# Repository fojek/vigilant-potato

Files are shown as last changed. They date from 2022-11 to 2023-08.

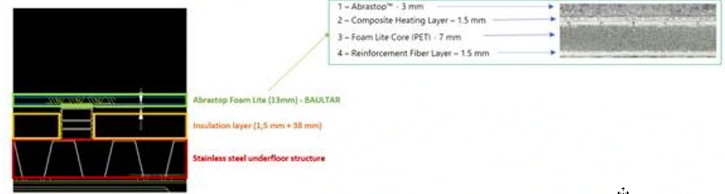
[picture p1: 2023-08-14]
Isolation WMATA.PNG

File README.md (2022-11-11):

# vigilant-potato
Capteur WiFi générique pour la cabane

* WIFI : ESP-12F ou ESP-M3
* MCU : Atmel ou ESP ou STM
* DC/DC à partir d'une alimentation 24V
* Adresse modifiable, par exemple DIP switch rotative

* Possibilité de lire: 
- distance ; 
- température ; 
- pression ;
- 2 entrées digitales ;

* Possibilité d'écrire :
- deux sorties relais?

Capteur ultrason modulaire (et autres capteurs)

Affichage de l'état : 
 - Vert clignotant : ON et en train de se connecter
 - Vert solide : ON et connecté
 - Autre led : Rouge si erreur (ou la même avec une autre séquence)
 - Autre led : trig effectué (distance)

Todo
- [ ] Déterminer un format
- [ ] Choisir ESP et MCU
- [ ] Choisir capteur ultrason
- [ ] Fabriquer PCB et tester

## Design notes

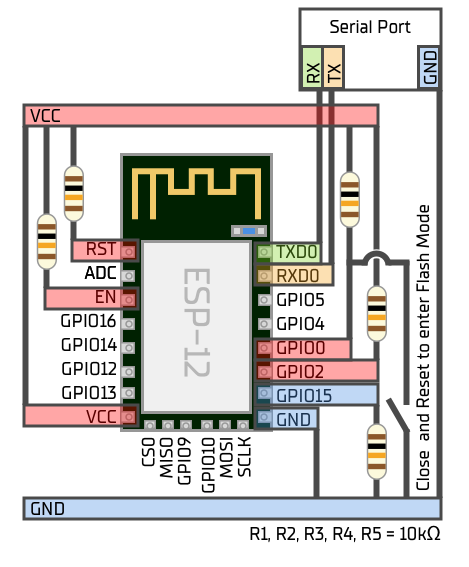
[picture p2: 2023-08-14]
Flash-ESP12.PNG

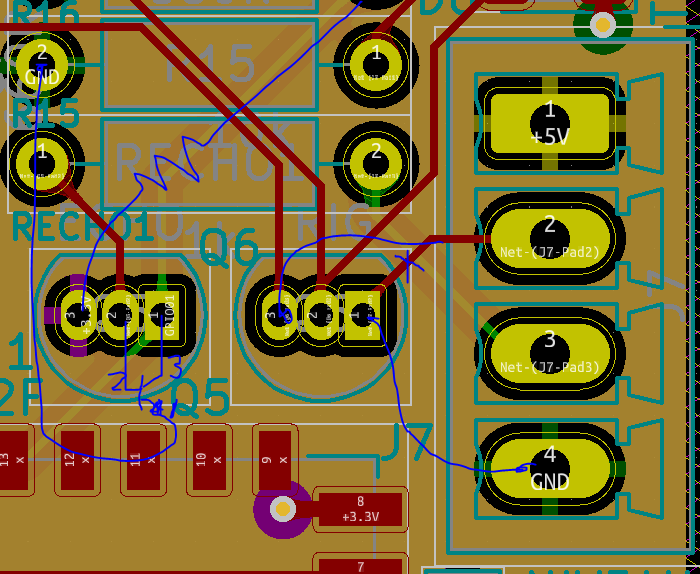
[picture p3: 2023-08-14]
modifs gerber.PNG

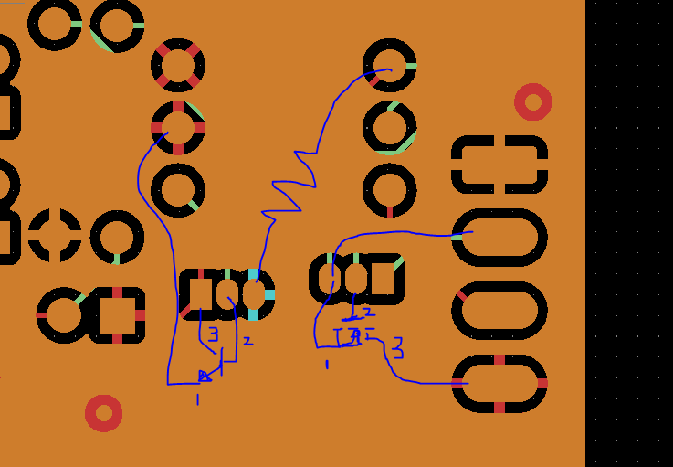
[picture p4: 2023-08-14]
modifs gerber (v1).PNG

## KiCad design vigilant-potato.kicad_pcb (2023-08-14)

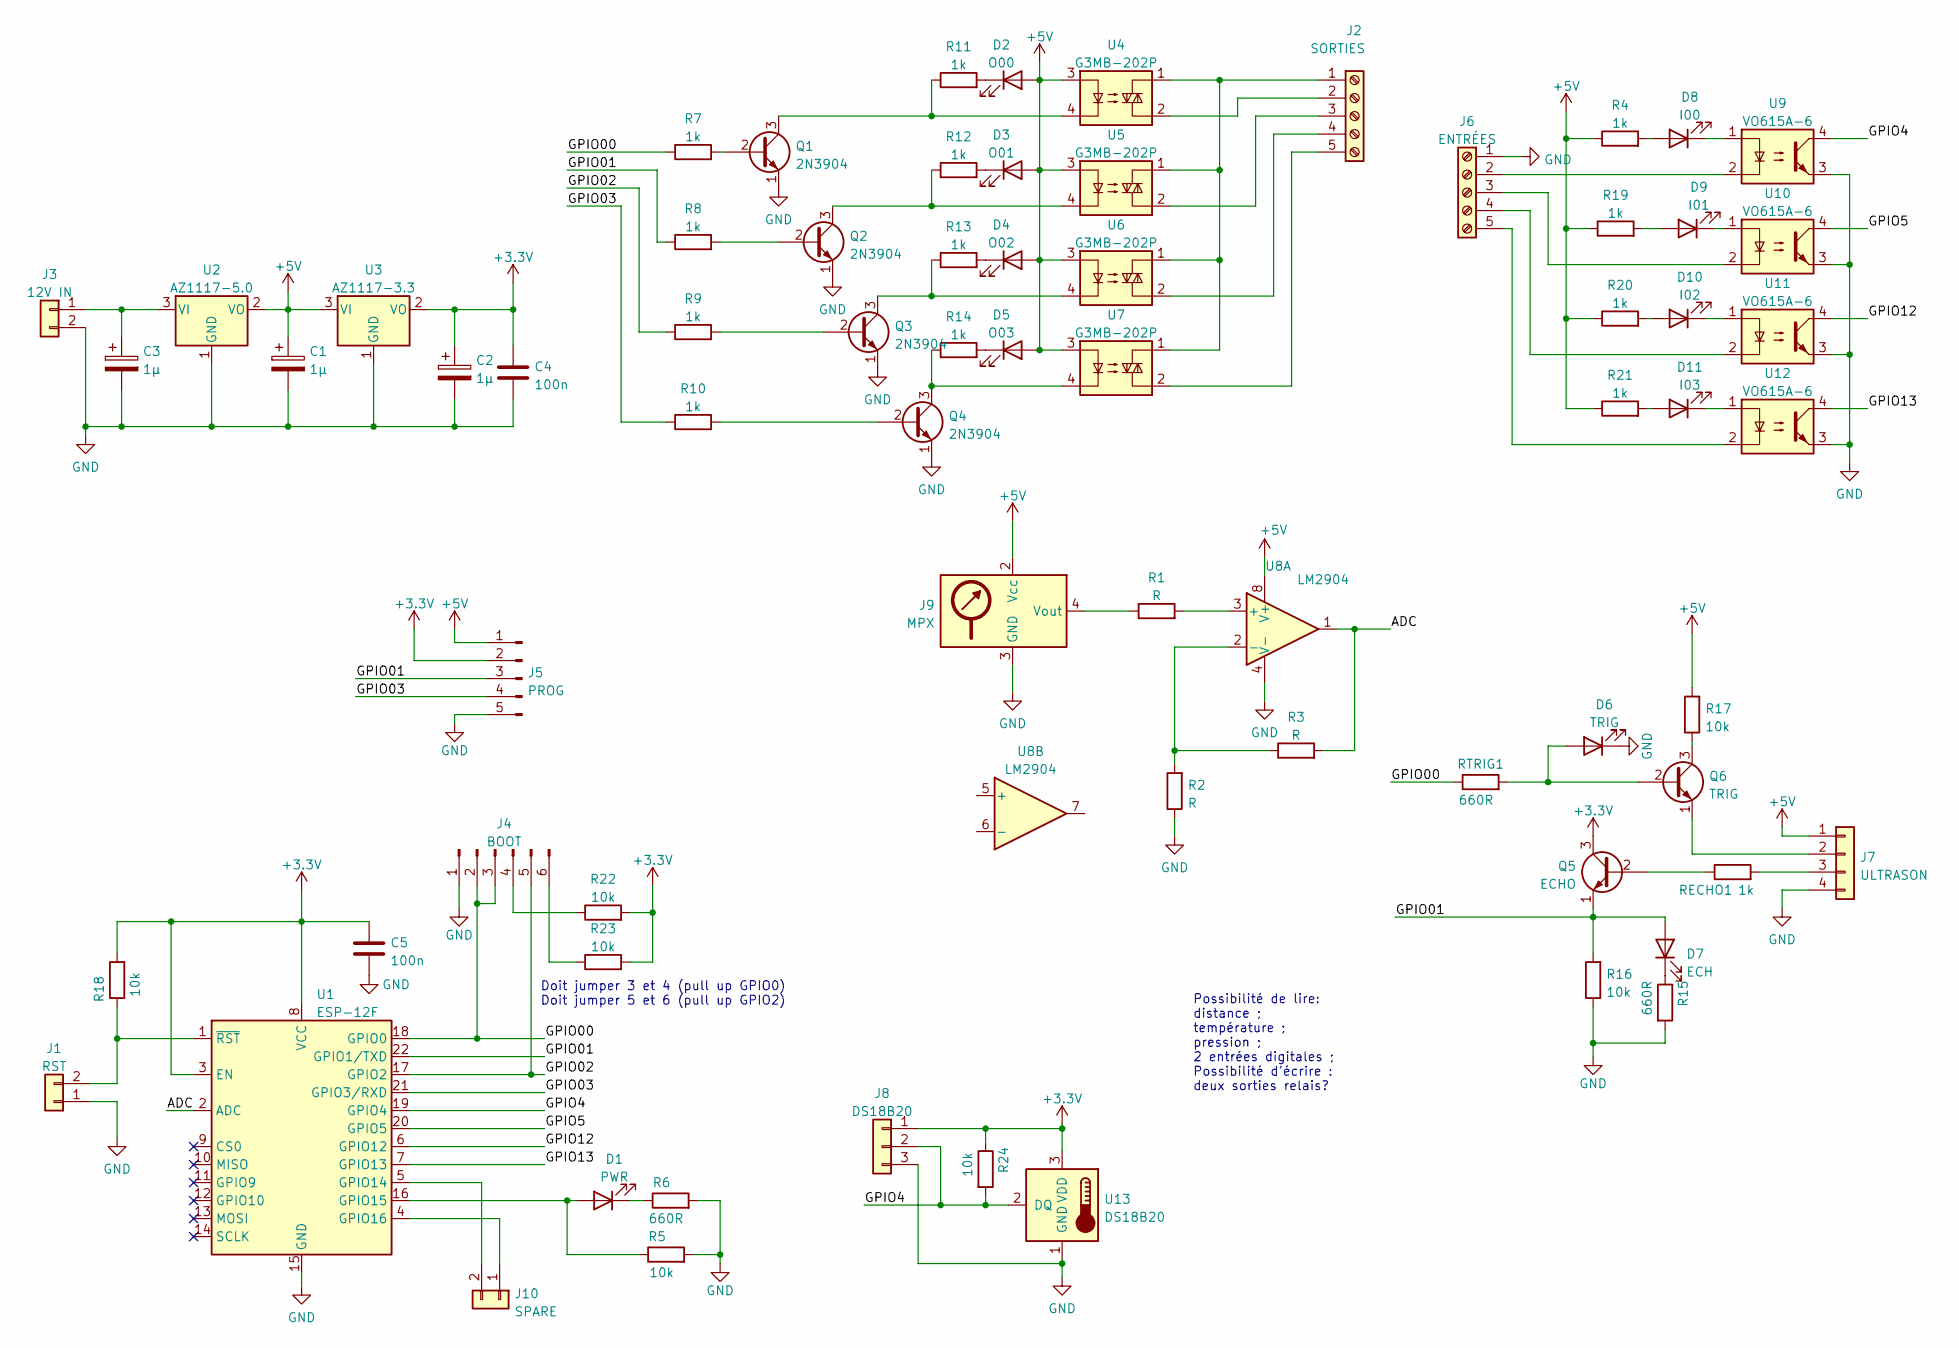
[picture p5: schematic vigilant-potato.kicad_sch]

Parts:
C1, C2, C3: 1µ; C_Rect_L7.0mm_W2.0mm_P5.00mm
C4, C5: 100n; C_Rect_L7.0mm_W2.0mm_P5.00mm
D1: PWR; LED_1206_3216Metric_Pad1.42x1.75mm_HandSolder
D2: O00; LED_1206_3216Metric_Pad1.42x1.75mm_HandSolder
D3: O01; LED_1206_3216Metric_Pad1.42x1.75mm_HandSolder
D4: O02; LED_1206_3216Metric_Pad1.42x1.75mm_HandSolder
D5: O03; LED_1206_3216Metric_Pad1.42x1.75mm_HandSolder
D6: TRIG; LED_1206_3216Metric_Pad1.42x1.75mm_HandSolder
D7: ECH; LED_1206_3216Metric_Pad1.42x1.75mm_HandSolder
D8: I00; LED_1206_3216Metric_Pad1.42x1.75mm_HandSolder
D9: I01; LED_1206_3216Metric_Pad1.42x1.75mm_HandSolder
D10: I02; LED_1206_3216Metric_Pad1.42x1.75mm_HandSolder
D11: I03; LED_1206_3216Metric_Pad1.42x1.75mm_HandSolder
J1: RST; PinHeader_1x02_P2.54mm_Vertical
J2: SORTIES; PhoenixContact_MCV_1,5_5-G-3.5_1x05_P3.50mm_Vertical; part EBRA-05-A
J3: 12V IN; PhoenixContact_MCV_1,5_2-G-3.5_1x02_P3.50mm_Vertical; part EBRA-02-A
J4: BOOT; PinHeader_1x06_P2.54mm_Vertical
J5: PROG; PinHeader_1x05_P2.54mm_Vertical
J6: ENTRÉES; PhoenixContact_MCV_1,5_5-G-3.5_1x05_P3.50mm_Vertical; part EBRA-05-A
J7: ULTRASON; PhoenixContact_MCV_1,5_4-G-3.5_1x04_P3.50mm_Vertical; part EBRA-04-A
J8: DS18B20; PinSocket_1x03_P2.54mm_Vertical
J9: MPX; PinHeader_1x06_P2.54mm_Vertical
J10: SPARE; PinHeader_1x02_P2.54mm_Vertical
Q1, Q2, Q3, Q4: 2N3904; TO-92_Inline
Q5: ECHO; TO-92_Inline
Q6: TRIG; TO-92_Inline
R1, R2, R3: R; R_Axial_DIN0207_L6.3mm_D2.5mm_P10.16mm_Horizontal
R4, R11, R12, R13, R14, R19, R20, R21: 1k; R_0805_2012Metric_Pad1.20x1.40mm_HandSolder
R5, R18, R22, R23: 10k; R_0805_2012Metric_Pad1.20x1.40mm_HandSolder
R6: 660R; R_0805_2012Metric_Pad1.20x1.40mm_HandSolder
R7, R8, R9, R10: 1k; R_Axial_DIN0207_L6.3mm_D2.5mm_P10.16mm_Horizontal
R15: 660R; R_Axial_DIN0207_L6.3mm_D2.5mm_P10.16mm_Horizontal
R16, R17, R24: 10k; R_Axial_DIN0207_L6.3mm_D2.5mm_P10.16mm_Horizontal
RECHO1: 1k; R_Axial_DIN0207_L6.3mm_D2.5mm_P10.16mm_Horizontal
RTRIG1: 660R; R_Axial_DIN0207_L6.3mm_D2.5mm_P10.16mm_Horizontal
U1: ESP-12F; ESP-12E
U2: AZ1117-5.0; TO-252-2
U3: AZ1117-3.3; TO-252-2
U4, U5, U6, U7: G3MB-202P
U8: LM2904; SOIC-8_3.9x4.9mm_P1.27mm
U9, U10, U11, U12: VO615A-6; DIP-4_W7.62mm
U13: DS18B20; TO-92_Inline

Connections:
+3.3V: C2.1, C4.1, C5.1, J5.2, J8.1, Q5.3 (C), R18.2, R22.2, R23.2, R24.1, U1.3 (EN), U1.8 (VCC), U3.2 (VO), U13.3 (VDD)
+5V: C1.1, D2.2 (A), D3.2 (A), D4.2 (A), D5.2 (A), J5.1, J7.1, J9.2 (Vcc), R4.1, R17.2, R19.1, R20.1, R21.1, U2.2 (VO), U3.3 (VI), U4.3, U5.3, U6.3, U7.3, U8.8 (V+)
/ADC: R3.2, U1.2 (ADC), U8.1
/GPIO00: J4.2, J4.3, R7.1, RTRIG1.1, U1.18 (GPIO0)
/GPIO01: D7.2 (A), J5.3, Q5.1 (E), R8.1, R16.2, U1.22 (GPIO1/TXD)
/GPIO02: J4.5, R9.1, U1.17 (GPIO2)
/GPIO03: J5.4, R10.1, U1.21 (GPIO3/RXD)
/GPIO4: J8.2, R24.2, U1.19 (GPIO4), U9.4, U13.2 (DQ)
/GPIO5: U1.20 (GPIO5), U10.4
/GPIO12: U1.6 (GPIO12), U11.4
/GPIO13: U1.7 (GPIO13), U12.4
GND: C1.2, C2.2, C3.2, C4.2, C5.2, D6.1 (K), J1.1, J3.2, J4.1, J5.5, J6.1, J7.4, J8.3, J9.3 (GND), Q1.1 (E), Q2.1 (E), Q3.1 (E), Q4.1 (E), R2.1, R5.2, R6.2, R15.2, R16.1, U1.15 (GND), U2.1 (GND), U3.1 (GND), U8.4 (V-), U9.3, U10.3, U11.3, U12.3, U13.1 (GND)
unnamed: C3.1, J3.1, U2.3 (VI)
unnamed: D1.1 (K), R6.1
unnamed: D1.2 (A), R5.1, U1.16 (GPIO15)
unnamed: D2.1 (K), R11.2
unnamed: D3.1 (K), R12.2
unnamed: D4.1 (K), R13.2
unnamed: D5.1 (K), R14.2
unnamed: D6.2 (A), Q6.2 (B), RTRIG1.2
unnamed: D7.1 (K), R15.1
unnamed: D8.1 (K), U9.1
unnamed: D8.2 (A), R4.2
unnamed: D9.1 (K), U10.1
unnamed: D9.2 (A), R19.2
unnamed: D10.1 (K), U11.1
unnamed: D10.2 (A), R20.2
unnamed: D11.1 (K), U12.1
unnamed: D11.2 (A), R21.2
unnamed: J1.2, R18.1, U1.1 (~RST)
unnamed: J2.1, U4.1, U5.1, U6.1, U7.1
unnamed: J2.2, U4.2
unnamed: J2.3, U5.2
unnamed: J2.4, U6.2
unnamed: J2.5, U7.2
unnamed: J4.4, R22.1
unnamed: J4.6, R23.1
unnamed: J6.2, U9.2
unnamed: J6.3, U10.2
unnamed: J6.4, U11.2
unnamed: J6.5, U12.2
unnamed: J7.2, Q6.1 (E)
unnamed: J7.3, RECHO1.2
unnamed: J9.4 (Vout), R1.1
unnamed: J10.1, U1.4 (GPIO16)
unnamed: J10.2, U1.5 (GPIO14)
unnamed: Q1.2 (B), R7.2
unnamed: Q1.3 (C), R11.1, U4.4
unnamed: Q2.2 (B), R8.2
unnamed: Q2.3 (C), R12.1, U5.4
unnamed: Q3.2 (B), R9.2
unnamed: Q3.3 (C), R13.1, U6.4
unnamed: Q4.2 (B), R10.2
unnamed: Q4.3 (C), R14.1, U7.4
unnamed: Q5.2 (B), RECHO1.1
unnamed: Q6.3 (C), R17.1
unnamed: R1.2, U8.3 (+)
unnamed: R2.2, R3.1, U8.2 (-)

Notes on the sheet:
Doit jumper 3 et 4 (pull up GPIO0) Doit jumper 5 et 6 (pull up GPIO2)
Possibilité de lire: distance ; température ; pression ; 2 entrées digitales ; Possibilité d'écrire : deux sorties relais?

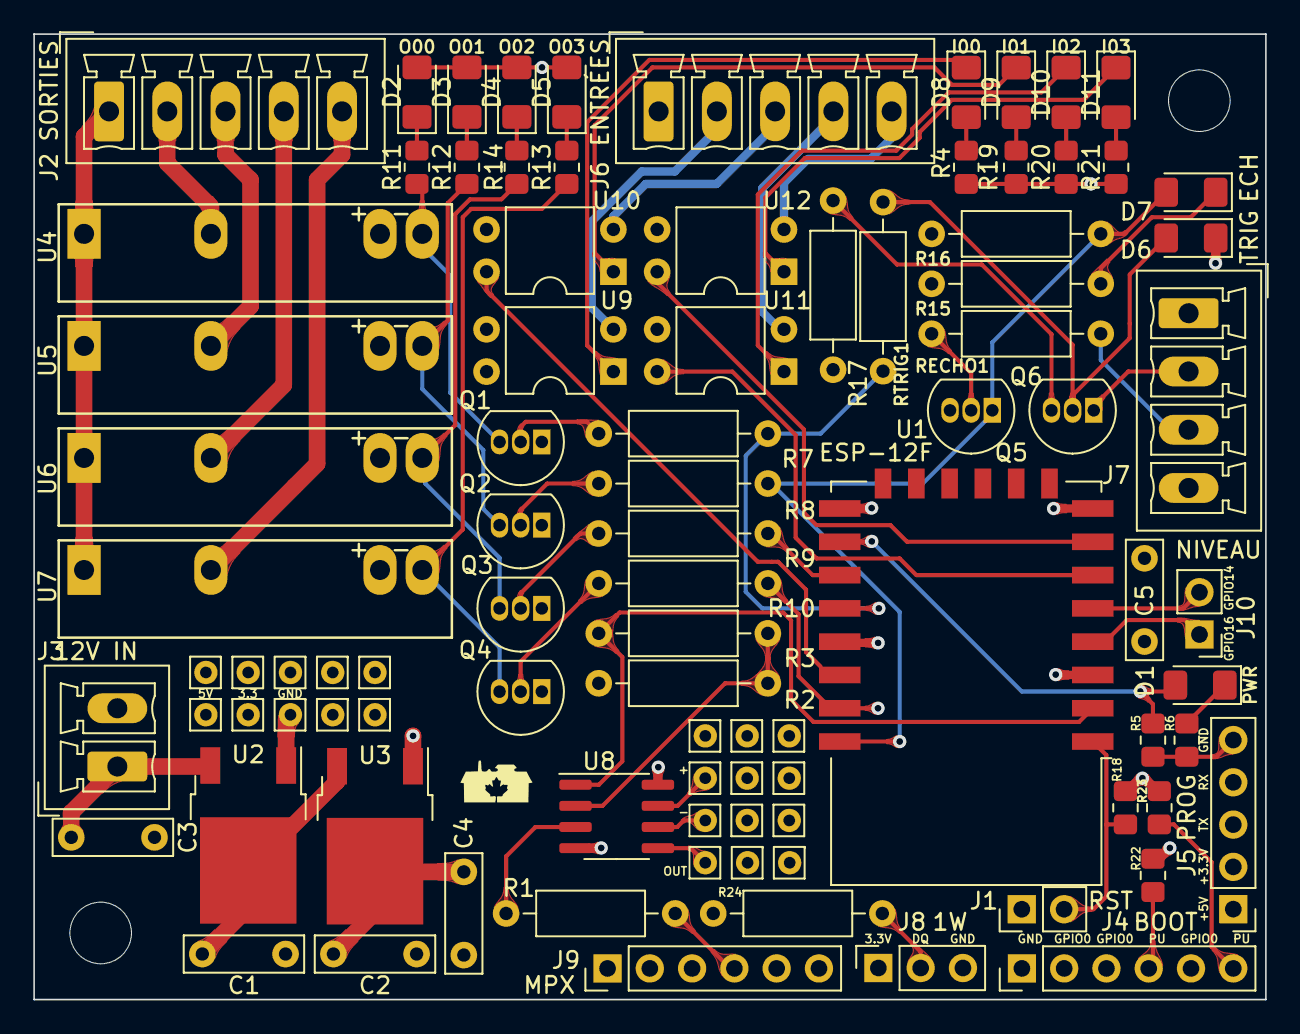
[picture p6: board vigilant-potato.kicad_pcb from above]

Board: 4 copper layers, 74.0 x 58.0 mm, 73 parts (0 on the bottom side), 58 nets.

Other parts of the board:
+: Pin_D0.7mm_L6.5mm_W1.8mm_FlatFork
-: Pin_D0.7mm_L6.5mm_W1.8mm_FlatFork
OUT: Pin_D0.7mm_L6.5mm_W1.8mm_FlatFork
